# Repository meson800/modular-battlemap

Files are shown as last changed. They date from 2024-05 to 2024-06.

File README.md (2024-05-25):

# modular-battlemap

# Goals
We want to make a modular battlemap system that:
- Consists of modular tiles, like 4x4 tiles at 25.4mm scale
- That tiles together with minimal whitespace
- That transmits power/data through the edges
- and is capable of arbitrarly lighting 4 RGB LEDs per square.
- can be powered / controlled from one "base map" tile, that has USB-C output.

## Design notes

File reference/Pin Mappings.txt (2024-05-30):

02 PC14 = OSC_IN (8 MHz resonator)
03 PC15 = OSC_OUT (8 MHz resonator)

04 VDD/VDDA = 3.3 V
05 VSS/VSSA = ground

06 NRST = reset circuit

7 PA0 = LED IN

19 PA9  = USART1_TX
20 PC6 = status LED
21 PA10 = USART1_RX
22 PA11 [PA9] = USART1_CTS
23 PA12 [PA10] = USART1_RTS

24 PA13 = SWDIO
25 PA14 = BOOT0 circuit and SWCLK

30 PB6 = I2C1_SCL
31 PB7 = I2C1_SDA

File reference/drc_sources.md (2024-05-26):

Design rules by fab house
=========================
- [OshPark design rules](https://docs.oshpark.com/design-tools/kicad/kicad-design-rules/)
- [JLBPCB user design rules](https://github.com/labtroll/KiCad-DesignRules)
- [JLBPCB specs](https://jlcpcb.com/capabilities/pcb-capabilities)

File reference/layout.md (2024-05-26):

Classic tutorials (Eagle)
=========================
- Read for the information, not for the actual software:
- [Basic board layout](https://learn.sparkfun.com/tutorials/using-eagle-board-layout)
- [SMD layout](https://learn.sparkfun.com/tutorials/designing-pcbs-advanced-smd/all)
- Sparkfun tutorials link to other sparkfun tutorials that are good, all the way back to "how to solder 101", "what is electricity", etc.

KiCAD information
=================
- [Getting started in KiCAD](https://docs.kicad.org/8.0/en/getting_started_in_kicad/getting_started_in_kicad.html)

General guiding tips
====================
- Minimize ratsnets intersections before placing footprints
- Assign power/ground traces to a net type that uses wider traces.
- For 2-layer boards, add ground pours to both sides. Remember to use vias to connect the ground planes together, especially islands.

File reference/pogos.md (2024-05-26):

- [Pogo mounting](https://www.ccpcontactprobes.com/application/7-mounting-options-spring-loaded-connectors-pogo-pins)

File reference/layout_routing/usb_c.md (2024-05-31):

Example from JLCPCB about how to tie the pins together: https://jlcpcb.com/blog/755-pcb-layout-guidelines-for-usb-type-c
- USB C example circuits: https://hackaday.com/2023/08/07/all-about-usb-c-example-circuits/
- FUSB302 example: https://hackaday.com/2023/02/14/all-about-usb-c-talking-low-level-pd/

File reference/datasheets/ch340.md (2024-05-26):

- [Reverse engineered footprint/schematic](https://web.archive.org/web/20231210065631/https://fobit.blogspot.com/2014/11/ch340g-in-eagle.html)

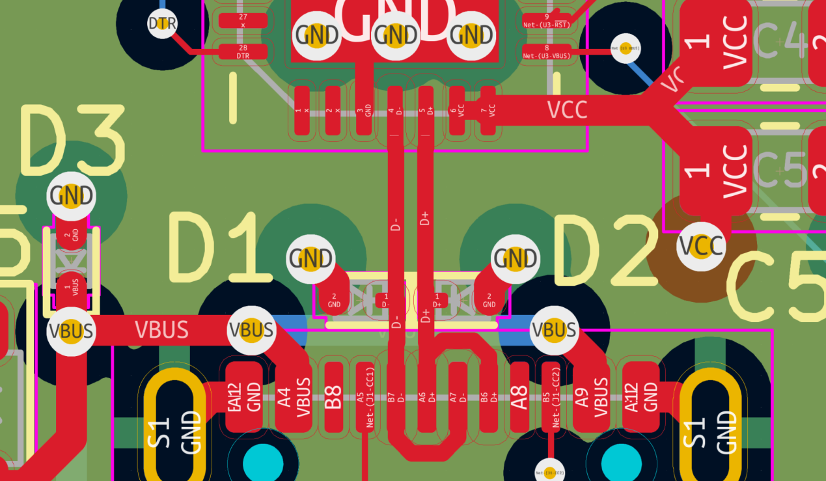
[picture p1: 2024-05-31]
reference/layout_routing/example_usb_c_routing.png

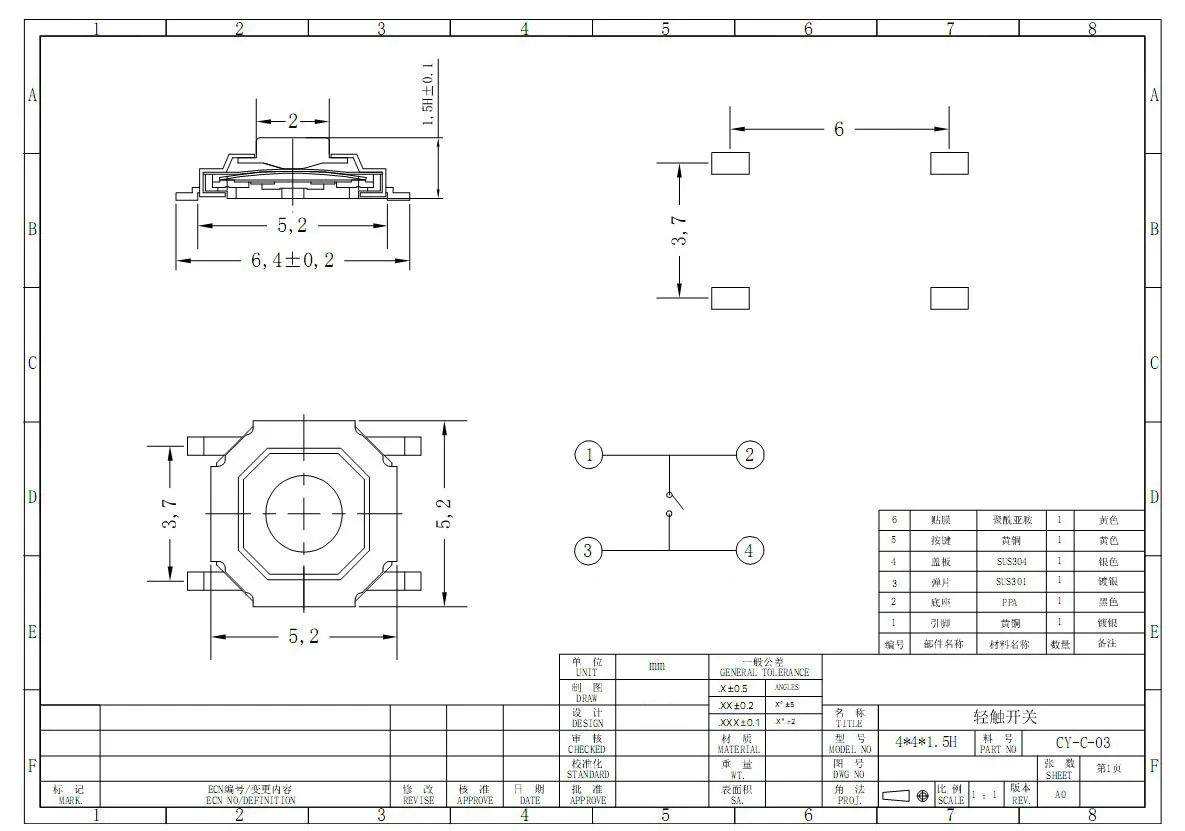
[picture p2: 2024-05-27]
reference/datasheets/micro_switch_diagram.png

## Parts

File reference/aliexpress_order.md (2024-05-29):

- Assorted 0603 (inch) resistors (came in the options 0402/0603/0805/1206/1210/2512, which are inch units)
- Assorted 0603 (inch) capacitors (came in the options 0402/0603/0805, which are inch units)
- 12 pF 0603 SMD capacitors
- 10pcs CH340G (SOP-16 package)
- LM2937IMP-3.3 L69B (SOT-223 package)
- 10pcs USB-C, 16pin
    - (Akiva) Suspect these are Molex 105450-0101 (or at least close enough for KiCAD
- 10pcs 12MHz crystasls (HC-49/S), https://www.aliexpress.us/item/3256805937336193.html
- 50pcs, 4mm x 4mm x 1.5mm micro switch pushbutton (https://www.aliexpress.us/item/3256805214225816.html)
    - (Chris) Pretty sure these are https://www.mouser.com/ProductDetail/CK/PTS526-SM15-SMTR2-LFS?qs=UXgszm6BlbENivbslIA%252B5g%3D%3D

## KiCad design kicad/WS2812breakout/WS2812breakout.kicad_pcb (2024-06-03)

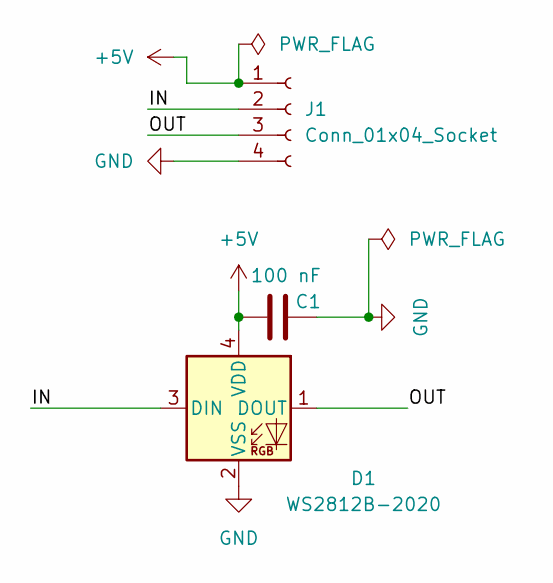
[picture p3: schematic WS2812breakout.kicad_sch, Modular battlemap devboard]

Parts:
C1: 100 nF; C_0603_1608Metric
D1: WS2812B-2020; LED_WS2812B-2020_PLCC4_2.0x2.0mm
J1: Conn_01x04_Socket; PinHeader_1x04_P2.54mm_Vertical

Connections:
+5V: C1.1, D1.4 (VDD), J1.1
/IN: D1.3 (DIN), J1.2
/OUT: D1.1 (DOUT), J1.3
GND: C1.2, D1.2 (VSS), J1.4

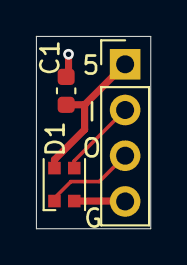
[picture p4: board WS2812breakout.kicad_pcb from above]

Board: 2 copper layers, 6.4 x 10.7 mm, 3 parts (0 on the bottom side), 4 nets.

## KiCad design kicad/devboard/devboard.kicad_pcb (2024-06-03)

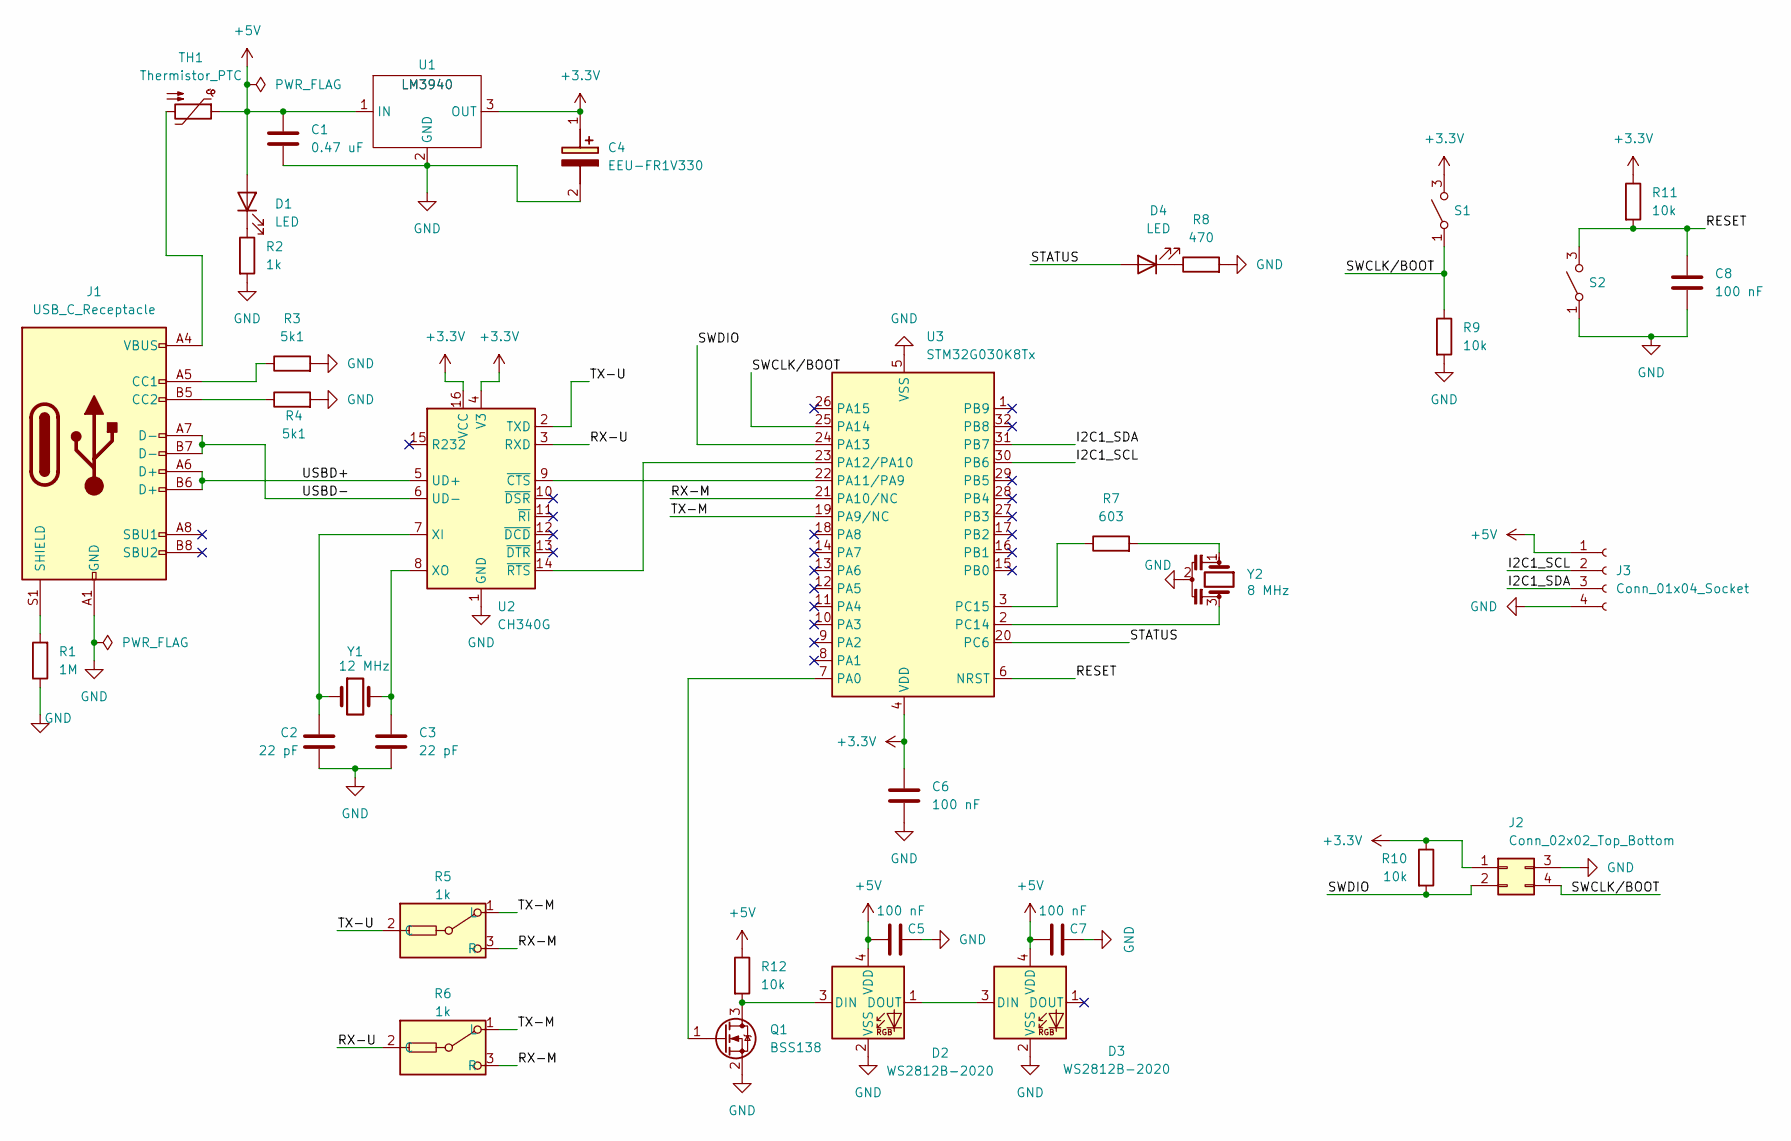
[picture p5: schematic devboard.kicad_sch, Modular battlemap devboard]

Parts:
C1: 0.47 uF; C_0603_1608Metric
C2, C3: 22 pF; C_0603_1608Metric
C4: EEU-FR1V330; EEU-FR1330; Mouser Part Number 667-EEU-FR1V330
C5, C6, C7, C8: 100 nF; C_0603_1608Metric
D1, D4: LED; LED_0603_1608Metric
D2, D3: WS2812B-2020; LED_WS2812B-2020_PLCC4_2.0x2.0mm
J1: USB_C_Receptacle; USB_C_Receptacle_Palconn_UTC16-G_pcb_edge
J2: Conn_02x02_Top_Bottom; PinHeader_2x02_P2.54mm_Vertical
J3: Conn_01x04_Socket; PinHeader_1x04_P2.54mm_Vertical
Q1: BSS138; SOT-23
R1: 1M; R_0603_1608Metric
R2: 1k; R_0603_1608Metric
R3, R4: 5k1; R_0603_1608Metric
R5, R6: 1k; resistor_3pad_switch_0603
R7: 603; R_0603_1608Metric
R8: 470; R_0603_1608Metric
R9, R10, R11, R12: 10k; R_0603_1608Metric
S1, S2: PTS526SM15SMTR2LFS; Mouser Part Number 611-PTS526SM15SMTR2L
TH1: Thermistor_PTC; Eaton PTS120616V025
U1: LM3940
U2: CH340G; SOIC-16_3.9x9.9mm_P1.27mm
U3: STM32G030K8Tx; LQFP-32_7x7mm_P0.8mm
Y1: 12 MHz; Crystal_HC49-4H_Vertical
Y2: 8 MHz; CSTNE16M0V530000R0; Mouser Part Number 81-CSTNE8M00G550000R

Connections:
+3.3V: C4.1 (+), C6.1, J2.1, R10.1, R11.1, S1.3, S1.4, U1.3 (OUT), U2.4 (V3), U2.16 (VCC), U3.4 (VDD)
+5V: C1.1, C5.1, C7.1, D1.2 (A), D2.4 (VDD), D3.4 (VDD), J3.1, R12.1, TH1.1, U1.1 (IN)
/I2C1_SCL: J3.2, U3.30 (PB6)
/I2C1_SDA: J3.3, U3.31 (PB7)
/RESET: C8.1, R11.2, S2.3, S2.4, U3.6 (NRST)
/RX-M: R5.3 (R), R6.3 (R), U3.21 (PA10/NC)
/RX-U: R6.2 (C), U2.3 (RXD)
/STATUS: D4.2 (A), U3.20 (PC6)
/SWCLK/BOOT: J2.4, R9.1, S1.1, S1.2, U3.25 (PA14)
/SWDIO: J2.2, R10.2, U3.24 (PA13)
/TX-M: R5.1 (L), R6.1 (L), U3.19 (PA9/NC)
/TX-U: R5.2 (C), U2.2 (TXD)
/USBD+: J1.A6 (D+), J1.B6 (D+), U2.5 (UD+)
/USBD-: J1.A7 (D-), J1.B7 (D-), U2.6 (UD-)
GND: C1.2, C2.2, C3.2, C4.2 (-), C5.2, C6.2, C7.2, C8.2, D2.2 (VSS), D3.2 (VSS), J1.A1 (GND), J1.A12 (GND), J1.B1 (GND), J1.B12 (GND), J2.3, J3.4, Q1.2 (S), R1.1, R2.2, R3.2, R4.2, R8.2, R9.2, S2.1, S2.2, U1.2 (GND), U1.4, U2.1 (GND), U3.5 (VSS), Y2.2
unnamed: D1.1 (K), R2.1
unnamed: D2.3 (DIN), Q1.3 (D), R12.2
unnamed: D2.1 (DOUT), D3.3 (DIN)
unnamed: D4.1 (K), R8.1
unnamed: J1.A5 (CC1), R3.1
unnamed: J1.B5 (CC2), R4.1
unnamed: J1.S1 (SHIELD), R1.2
unnamed: J1.A4 (VBUS), J1.A9 (VBUS), J1.B4 (VBUS), J1.B9 (VBUS), TH1.2
unnamed: Q1.1 (G), U3.7 (PA0)
unnamed: R7.2, Y2.1
unnamed: C2.1, U2.7 (XI), Y1.1
unnamed: C3.1, U2.8 (XO), Y1.2
unnamed: U2.9 (~CTS), U3.22 (PA11/PA9)
unnamed: U2.14 (~RTS), U3.23 (PA12/PA10)
unnamed: U3.2 (PC14), Y2.3
unnamed: R7.1, U3.3 (PC15)

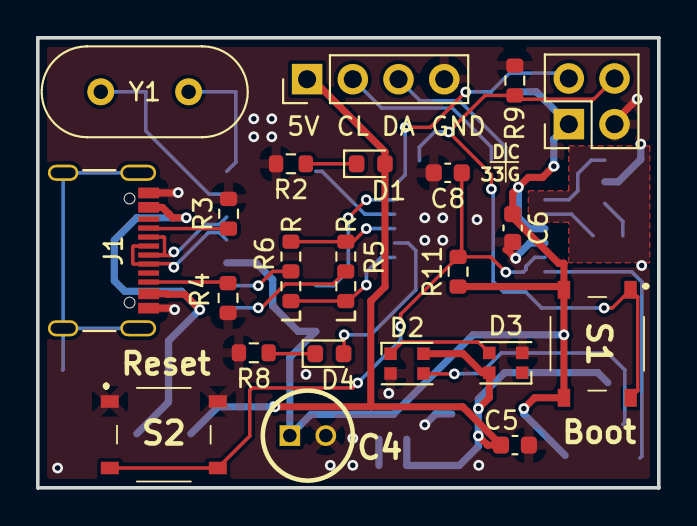
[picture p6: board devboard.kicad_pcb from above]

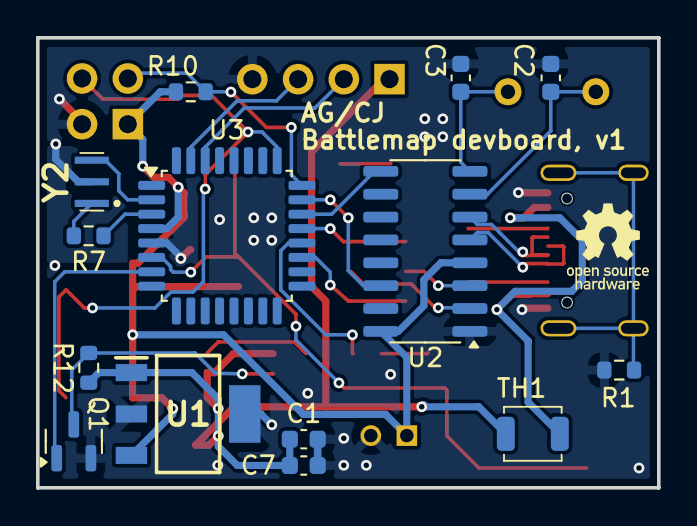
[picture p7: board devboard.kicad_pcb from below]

Board: 2 copper layers, 34.5 x 25.0 mm, 36 parts (14 on the bottom side), 31 nets.

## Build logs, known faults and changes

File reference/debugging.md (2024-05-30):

- SWD circuit reference https://developer.arm.com/documentation/101761/1-0/Debug-and-trace-interface/Typical-SWD-circuit

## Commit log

2024-05-27 Initial kicad commit
    [devboard.kicad_pcb, devboard.kicad_sch, modular_battlemap.kicad_pcb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]
2024-05-27 Create Pin Mappings.txt
2024-05-27 Update Pin Mappings.txt
2024-05-27 Version 1 of the schematic
    [devboard.kicad_pcb, devboard.kicad_sch]
2024-05-27 Added aliexpress order info, removed modular battlemap
    [modular_battlemap.kicad_pcb, modular_battlemap.kicad_sch]
2024-05-29 added many many footprints
    [devboard.kicad_sch]
2024-05-29 all but thermistor footprint added
    [devboard.kicad_sch]
2024-05-30 Updated footprint assignments and schematic
    [devboard.kicad_sch]
2024-05-30 Added pin headers for SWD
    [devboard.kicad_pcb, devboard.kicad_sch]
2024-05-30 Updated boot/swclk net name
    [devboard.kicad_sch]
2024-05-30 updated footprints for Y1, C2
    [devboard.kicad_sch]
2024-05-30 All footprints done?
    [devboard.kicad_pcb, devboard.kicad_sch]
2024-05-30 fixed footprint for crystal
    [devboard.kicad_sch]
2024-05-30 Added new 16-pin USB C symbol, updated PCB
    [devboard.kicad_pcb, devboard.kicad_sch]
2024-05-31 Try placing more components on the board
    [devboard.kicad_pcb]
2024-05-31 Move connectors to the top
    [devboard.kicad_pcb]
2024-05-31 Added 3pad resistor comment, and spread the board out
    [devboard.kicad_pcb, devboard.kicad_sch]
2024-05-31 Placed components within shape
    it's messy but it fits
    [devboard.kicad_pcb]
2024-05-31 started wiring
    [devboard.kicad_pcb]
2024-06-01 Added MOSFET to drive LEDs
    [devboard.kicad_sch]
2024-06-02 integrated and added transistor to pcb
    [devboard.kicad_pcb]
2024-06-02 reconfigured slightly
    [devboard.kicad_pcb]
2024-06-02 mostly routed
    [devboard.kicad_pcb]
2024-06-02 Updated fresh layout of pieces
    [devboard.kicad_pcb]
2024-06-02 created WS2812 breakout board
    [WS2812breakout.kicad_pcb, WS2812breakout.kicad_sch]
2024-06-02 Added most routing, besides the debug header
    [devboard.kicad_pcb, devboard.kicad_sch]
2024-06-02 routed remaining components
    [devboard.kicad_pcb]
2024-06-02 updated breakout schematic to include in/out lines
    [WS2812breakout.kicad_pcb, WS2812breakout.kicad_sch]
2024-06-02 Fixed USB routing, simplified other routes
    [devboard.kicad_pcb, devboard.kicad_sch]
2024-06-02 Routed and Prettied-up breakout board
    [WS2812breakout.kicad_pcb]
2024-06-02 Added ground plane, fully routed
    [devboard.kicad_pcb]
2024-06-02 Finalized, fixing all ERC and DRC warnings
    [devboard.kicad_pcb, devboard.kicad_sch]
2024-06-02 Move the C4 label
    [devboard.kicad_pcb]
2024-06-02 niche GND prettying up
    [devboard.kicad_pcb]
2024-06-03 Added silkscreen labels
    [devboard.kicad_pcb]
2024-06-03 Updated silkscreen for breakout
    [WS2812breakout.kicad_pcb]
2024-06-03 final fixes
    [WS2812breakout.kicad_pcb, WS2812breakout.kicad_sch, devboard.kicad_pcb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]
